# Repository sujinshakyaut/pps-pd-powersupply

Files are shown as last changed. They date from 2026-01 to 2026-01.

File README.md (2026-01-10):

# USB-CPS Power Supply



## Highlights

- USB-C Power Delivery breakout board based on the **PPS protocol** and PD capabilities of USB-C.
- Programmable, regulated output from **5 V to 24 V**
- Dynamic voltage and current negotiation with **PD-compliant chargers**
- Simple **I²C interface** for configuration and real-time monitoring
- Built-in protection by AP33772S: **OVP, UVP, OCP, and OTP**

---

## Libraries

- [Arduino Library (CentyLab)](https://github.com/CentyLab/AP33772S-CentyLab?utm_source=chatgpt.com)


- [AP33772S PD Controller Sink Datasheet (Diodes Inc)](https://www.diodes.com/datasheet/download/AP33772S.pdf?utm_source=chatgpt.com)  
- [Breakout Board Evaluation Board Guide)](https://www.diodes.com/assets/Evaluation-Boards/AP33772S-Sink-Controller-EVB-User-Guide.pdf)

---

## Requirements for AVS

To utilize the **AVS (Adjustable Voltage Supply)** profile, you need a **USB-C charger or power bank that supports AVS** and a **high-power USB-C cable rated for at least 240 W**. Compatible devices we have tested include:

- **Framework Laptop Charger** – 180 W  
- **AMEGAT Powerbank** – 140 W  
- **Baseus Powerbank** – 140 W  
- **UGREEN Nexode** – 300 W  

Using a non-AVS charger or an insufficient cable may prevent proper voltage negotiation or limit maximu

## Description

The **I²C-Enabled USB-C Power Supply** is a programmable DC power source built around the **AP33772S USB Type-C® PD 3.1 sink controller**. It converts a standard USB-C Power Delivery adapter into an adjustable output supply, supporting **PPS (up to 21 V)** and **EPR/AVS (up to 28 V)** for flexible, standards-compliant power delivery.

All USB-PD negotiation is handled by the AP33772S, allowing an external microcontroller to configure voltage, current, and protection thresholds through a simple **I²C interface**—no USB-PD firmware required. The board integrates essential safety features including **OVP, UVP, OCP, OTP** and external NTC-based thermal monitoring.

Status feedback is provided via an onboard **PD status LED**, making the board well suited for programmable power supplies, embedded systems, and USB-C PD development.

---

## Easy I²C Control

The board exposes a **register-based I²C interface** for full configuration and monitoring. The host MCU can programmatically:

- Set precise output voltage and current limits according to the PD contract  
- Query negotiated PD parameters, including voltage, current, and power delivery status  
- Monitor real-time fault conditions and protection events (OVP, UVP, OCP, OTP)  

All USB-PD negotiation and safety enforcement are managed internally by the **AP33772S**, allowing the MCU to focus on application-level control without handling the PD protocol stack.

---

Specifications

- **Output Voltage:** 5 V – 24 V (PPS), dynamically adjustable via I²C  
- **Power Delivery Support:** USB-C PD 3.1 with PPS and SPR/EPR profiles  
- **Maximum Current:** Dependent on PD contract and charger capabilities  
- **Protection Features:** Over-Voltage (OVP), Under-Voltage (UVP), Over-Current (OCP), Over-Temperature (OTP)  
- **Control Interface:** I²C (register-based) for configuration and monitoring  
- **Input Source:** USB-C PD-compliant charger  
- **Status Indicators:** LED for PD negotiation, FLIP pin for cable orientation detection

---

## Author

**Sujin Shakya**  
GitHub: https://github.com/sujinshakyaut

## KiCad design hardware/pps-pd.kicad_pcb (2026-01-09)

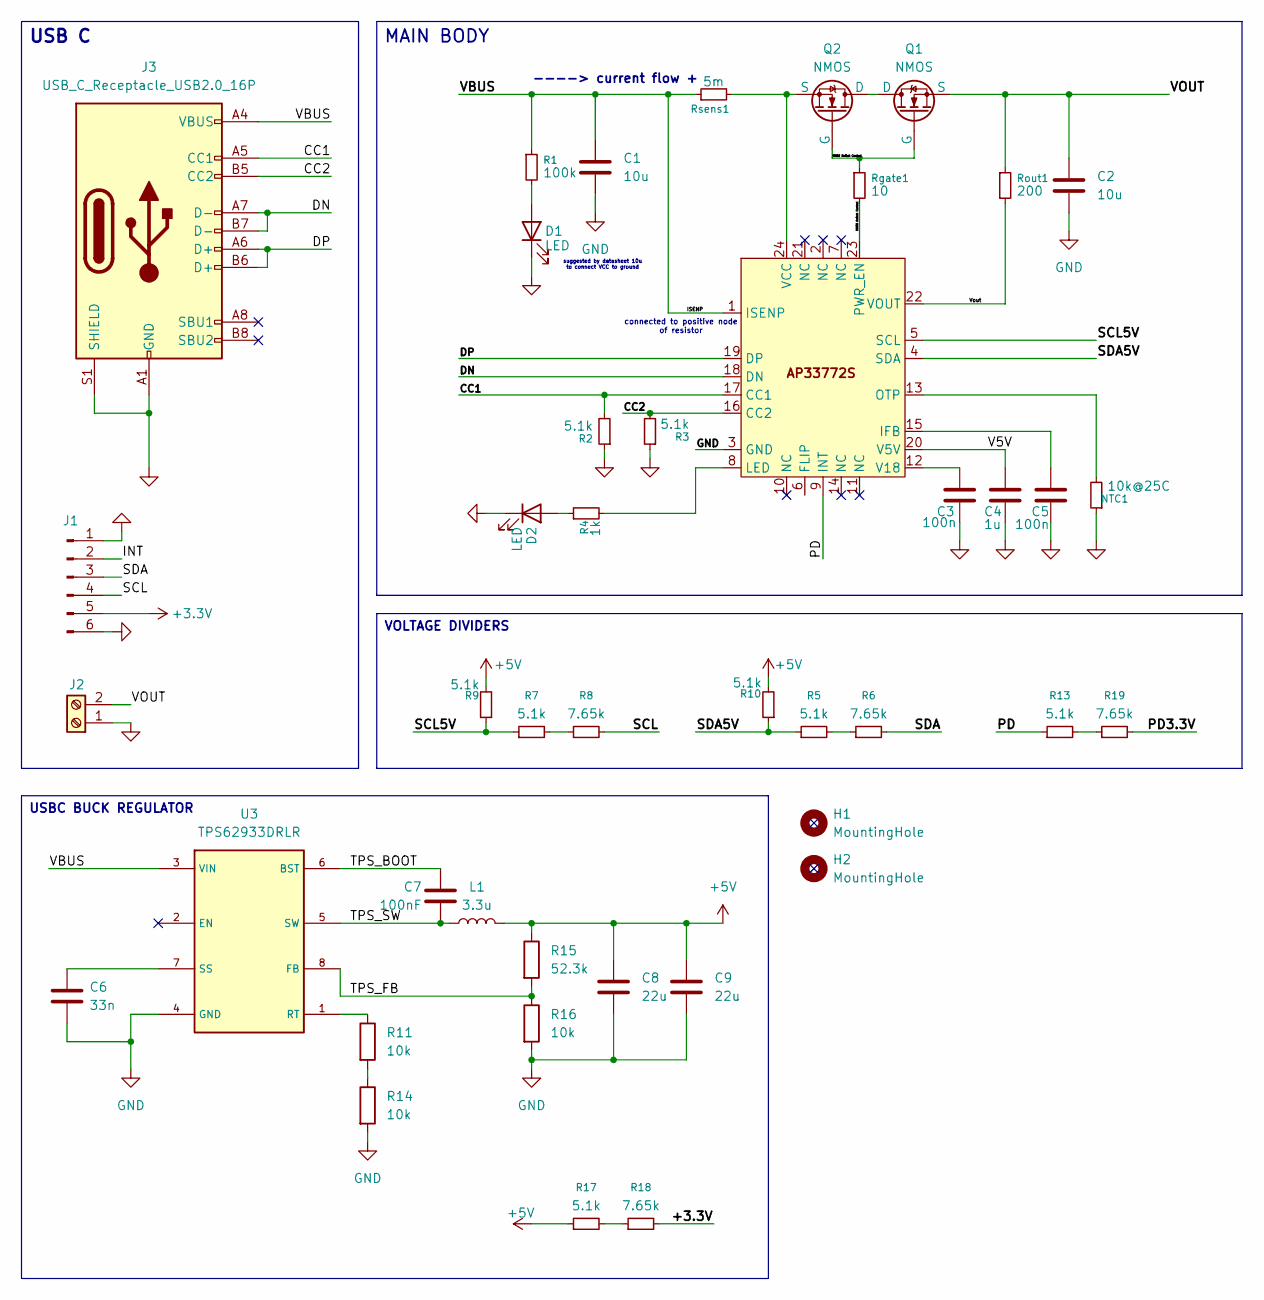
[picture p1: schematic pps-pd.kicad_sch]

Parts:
C1, C2: 10u; C_0402_1005Metric
C3, C5: 100n; C_0402_1005Metric
C4: 1u; C_0402_1005Metric
C6: 33n; C_0603_1608Metric; LCSC C21117
C7: 100nF; C_0402_1005Metric; LCSC C1525
C8, C9: 22u; C_0805_2012Metric; LCSC C45783
D1, D2: LED; LED_0603_1608Metric
H1, H2: MountingHole; MountingHole_2.7mm_M2.5_DIN965_Pad_TopBottom
J1: Conn_01x06_Pin; PinHeader_1x08_P2.54mm_Vertical
J2: Screw_Terminal_5mm; TerminalBlock_Phoenix_MKDS-1,5-2_1x02_P5.00mm_Horizontal
J3: USB_C_Receptacle_USB2.0_16P; USB_C_Receptacle_GCT_USB4105-xx-A_16P_TopMnt_Horizontal
L1: 3.3u; L_Bourns_SRP7028A_7.3x6.6mm
NTC1: 10k@25C; R_0402_1005Metric
Q1, Q2: NMOS; DFN-8-1EP_3x3mm_P0.5mm_EP1.65x2.38mm
R1: 100k; R_0402_1005Metric
R2, R3, R5, R7, R9, R10, R13, R17: 5.1k; R_0402_1005Metric
R4: 1k; R_0402_1005Metric
R6, R8, R18, R19: 7.65k; R_0402_1005Metric
R11, R14, R16: 10k; R_0402_1005Metric; LCSC C25744
R15: 52.3k; R_0402_1005Metric; LCSC C103091
Rgate1: 10; R_0402_1005Metric
Rout1: 200; R_0402_1005Metric
Rsens1: 5m; R_0402_1005Metric
U1: AP33772S; PD Sink IC
U3: TPS62933DRLR; SOT-583-8

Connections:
+3.3V: J1.5, R18.2
+5V: C8.1, C9.1, L1.2, R9.2, R10.2, R15.1, R17.1
/CC1: J3.A5 (CC1), R2.2, U1.17 (CC1)
/CC2: J3.B5 (CC2), R3.2, U1.16 (CC2)
/DN: J3.A7 (D-), J3.B7 (D-), U1.18 (DN)
/DP: J3.A6 (D+), J3.B6 (D+), U1.19 (DP)
/INT: J1.2
/ISENP: C1.1, J3.A4 (VBUS), J3.A9 (VBUS), J3.B4 (VBUS), J3.B9 (VBUS), R1.1, Rsens1.1, U1.1 (ISENP), U3.3 (VIN)
/NMOS Switch Control: Q1.2 (G), Q2.2 (G), Rgate1.1, Rgate1.2, U1.23 (PWR_EN)
/PD: R13.1, U1.9 (INT)
/PD3.3V: R19.2
/SCL: J1.4, R8.2
/SCL5V: R7.1, R9.1, U1.5 (SCL)
/SDA: J1.3, R6.2
/SDA5V: R5.1, R10.1, U1.4 (SDA)
/TPS_BOOT: C7.1, U3.6 (BST)
/TPS_FB: R15.2, R16.1, U3.8 (FB)
/TPS_SW: C7.2, L1.1, U3.5 (SW)
/V5V: C4.1, U1.20 (V5V)
/VOUT: C2.1, J2.2, Q1.3 (S), Rout1.1
/Vout: Rout1.2, U1.22 (VOUT)
GND: C1.2, C2.2, C3.2, C4.2, C5.2, C6.2, C8.2, C9.2, D1.1 (K), D2.1 (K), J1.1, J1.6, J2.1, J3.A1 (GND), J3.A12 (GND), J3.B1 (GND), J3.B12 (GND), J3.S1 (SHIELD), NTC1.1, R2.1, R3.1, R14.2, R16.2, U1.3 (GND), U3.4 (GND)
unnamed: D1.2 (A), R1.2
unnamed: D2.2 (A), R4.1
unnamed: Q1.1 (D), Q2.1 (D)
unnamed: Q2.3 (S), Rsens1.2, U1.24 (VCC)
unnamed: R5.2, R6.1
unnamed: R7.2, R8.1
unnamed: R11.2, R14.1
unnamed: R13.2, R19.1
unnamed: R17.2, R18.1
unnamed: C5.1, U1.15 (IFB)
unnamed: R4.2, U1.8 (LED)
unnamed: NTC1.2, U1.13 (OTP)
unnamed: C3.1, U1.12 (V18)
unnamed: R11.1, U3.1 (RT)
unnamed: C6.1, U3.7 (SS)

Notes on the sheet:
----> current flow +
connected to positive node of resistor
suggested by datasheet 10u to connect VCC to ground
MAIN BODY
USBC BUCK REGULATOR
VOLTAGE DIVIDERS
USB C

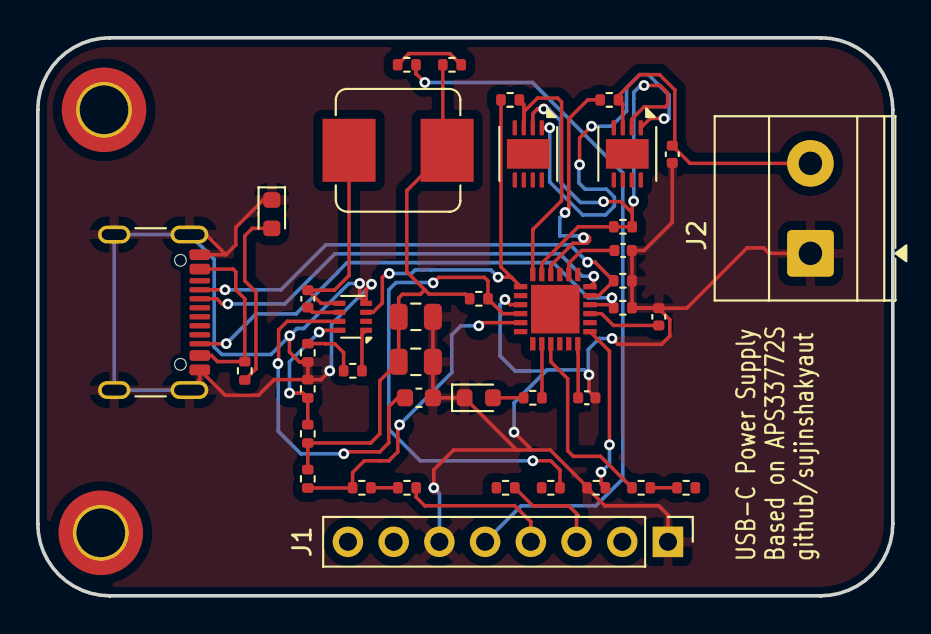
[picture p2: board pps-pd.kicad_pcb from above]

Board: 2 copper layers, 47.5 x 31.0 mm, 42 parts (0 on the bottom side), 35 nets.

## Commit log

2025-12-28 kicad files
    [PD from USBC.kicad_pcb, PD from USBC.kicad_sch]
2026-01-07 V1-demo-breakout
    test board
    [PD from USBC.kicad_pcb, PD from USBC.kicad_sch, pps-pd.kicad_pcb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]
2026-01-09 final update
    fixed layout issues
    [usbc-power.kicad_pcb, usbc-power.kicad_sch]
